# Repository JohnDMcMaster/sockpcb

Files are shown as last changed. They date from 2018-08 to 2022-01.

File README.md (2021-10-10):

# sockext

Chip socket extension cable adapters.
They are primarily intended to be high quality fixtures for invasive chip analysis such as microprobing, laser fault injection, and EM SCA.

Example: BP Microsystems programmers are high quality but physically large.
Unfortunately this large size precludes it from being used to read out a chip on my probe station.
Solution: extend the socket from the programmer via ribbon cable to an adapter board on the probe station (dipext-pin + dipext-sock + cable).

Projects:
  * dipext-sock: converts an IDC connector to a ZIF40 socket. Also adds patch connections
  * dipext-pin: converts DIP40 pins into an IDC connector. Also adds patch connections
  * dipext-pin-r: like above but flips pins for backside analysis
    * WARNING: not updated for new pin order
  * dipspy: patch a chip similar to dipext-sock + dipext-pin w/o cables and such
    * FIXME: needs rev to use SMD to make solder easier

IMPORTANT: pin order was swapped at this rev to match crimp connectors:
  * dipext-sock_r3
  * dipext-pin_r6
  * WARNING: dipext-pin-r_r1 is not compatible / updated yet

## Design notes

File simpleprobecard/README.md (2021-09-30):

# Simple microprobing breakout thing for 0.5mm wide probes
Hole is parametric, can be cut to any size.
Mounting points are on a standard 1" grid.
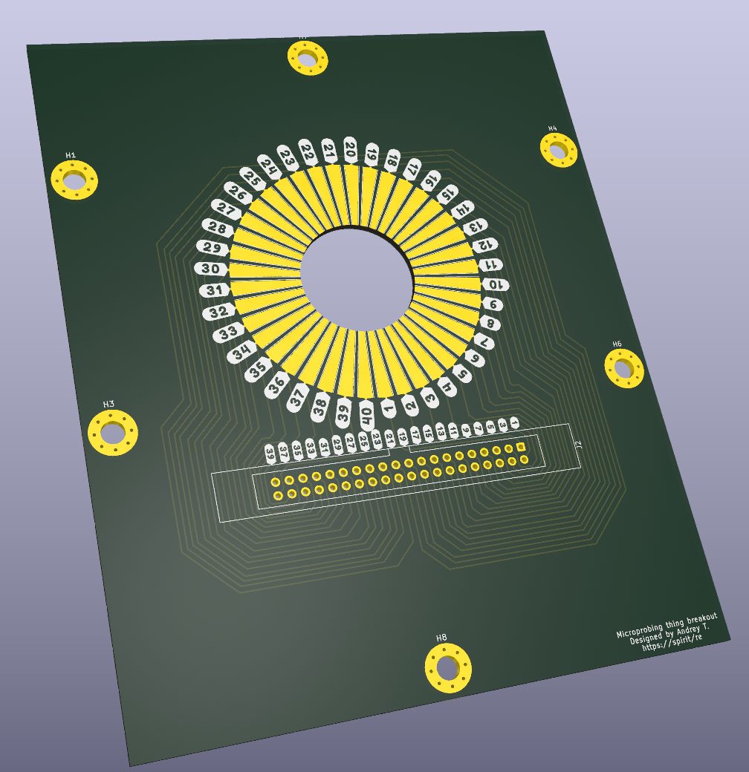
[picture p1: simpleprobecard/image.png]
Render


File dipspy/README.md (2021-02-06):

# dipspy
DIP40 signal parallel and series signal tap.
Usually you'll want jumpers in the center positions to connect the two sockets together.
Alternatively install a current probe, feed in an external signal, etc.
Logic analyzers can be easily attached to the extra pins

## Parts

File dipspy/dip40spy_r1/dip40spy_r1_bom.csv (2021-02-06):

Manufacturer Part Number | Manufacturer | Digi-Key Part Number | Customer Reference | Reference Designator | Packaging | Part Status | Quantity | Unit Price | Extended Price | Quantity Available | Mfg Std Lead Time | Description | RoHS Status | Lead Free Status | REACH Status
CD74HC4050M96 | Texas Instruments | 296-14529-1-ND |  |  | Cut Tape (CT) | Active | 2 | 0.46000 | $0.92 | 22280 | 6 Weeks | IC BUFFER NON-INVERT 6V 16SOIC | RoHS Compliant | Lead free | REACH Unaffected
150060BS75000 | Wurth Electronics Inc. | 732-4966-1-ND |  |  | Cut Tape (CT) | Active | 1 | 0.15000 | $0.15 | 31400 | 10 Weeks | LED BLUE CLEAR 0603 SMD | RoHS Compliant | Lead free | REACH Unaffected
150060VS75000 | Wurth Electronics Inc. | 732-4980-1-ND |  |  | Cut Tape (CT) | Active | 1 | 0.14000 | $0.14 | 53972 | 10 Weeks | LED GREEN CLEAR 0603 SMD | RoHS Compliant | Lead free | REACH Unaffected
SS-60000-008 | Stewart Connector | 380-1095-ND |  |  | Tray | Active | 6 | 3.02000 | $18.12 | 6441 | 16 Weeks | CONN MOD JACK 8P8C VERT SHIELDED | RoHS Compliant | Lead free | REACH Unaffected
TSW-123-07-F-D | Samtec Inc. | SAM12366-ND |  |  | Bulk | Active | 2 | 2.88000 | $5.76 | 264 | 3 Weeks | .025" SQ. TERMINAL STRIPS | RoHS Compliant | Lead free | REACH Unaffected

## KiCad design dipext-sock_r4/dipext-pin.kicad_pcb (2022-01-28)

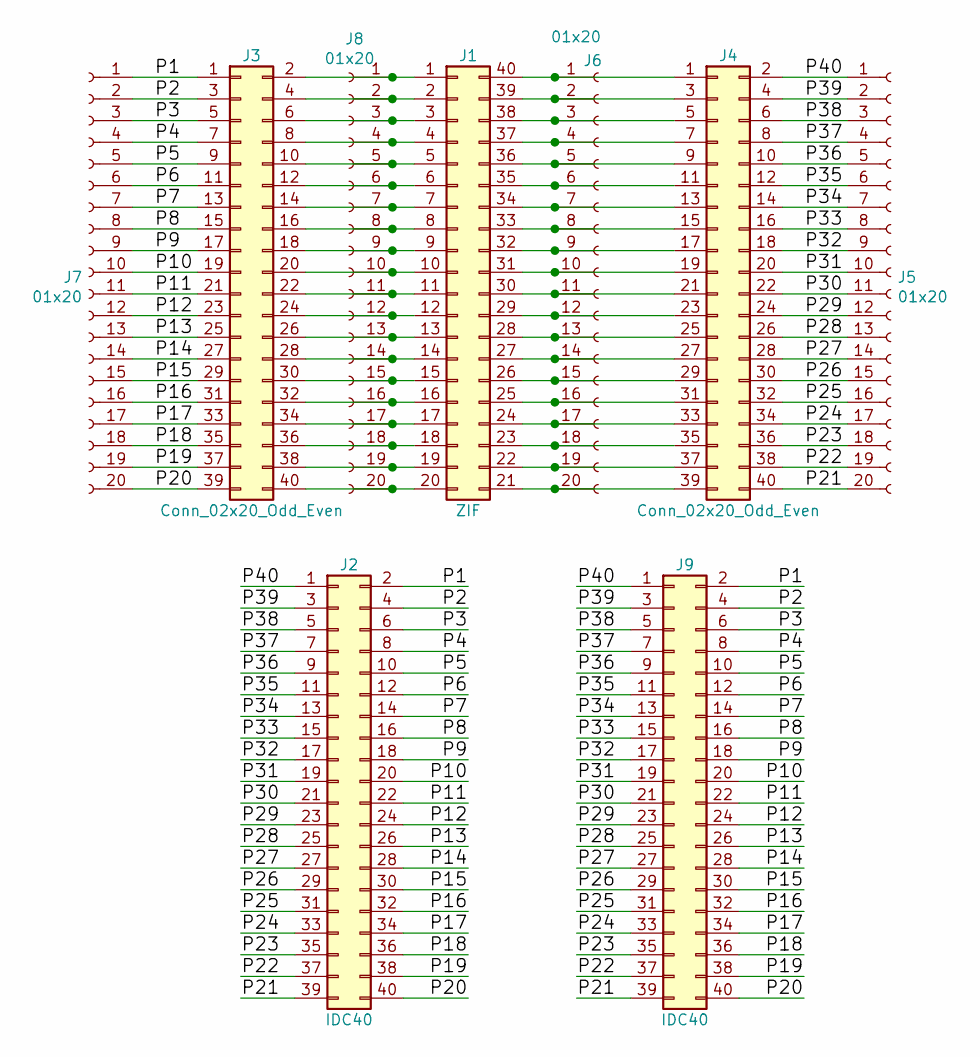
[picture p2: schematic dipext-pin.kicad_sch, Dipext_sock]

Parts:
J1: ZIF; mydip40
J2, J9: IDC40; IDC-Header_2x20_P2.54mm_Latch_Vertical
J3, J4: Conn_02x20_Odd_Even; Pin_Header_Straight_2x20_Pitch2.54mm
J5, J6, J7, J8: 01x20; PinHeader_1x20_P2.54mm_Vertical

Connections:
/P1: J2.2, J3.1, J7.1, J9.2
/P2: J2.4, J3.3, J7.2, J9.4
/P3: J2.6, J3.5, J7.3, J9.6
/P4: J2.8, J3.7, J7.4, J9.8
/P5: J2.10, J3.9, J7.5, J9.10
/P6: J2.12, J3.11, J7.6, J9.12
/P7: J2.14, J3.13, J7.7, J9.14
/P8: J2.16, J3.15, J7.8, J9.16
/P9: J2.18, J3.17, J7.9, J9.18
/P10: J2.20, J3.19, J7.10, J9.20
/P11: J2.22, J3.21, J7.11, J9.22
/P12: J2.24, J3.23, J7.12, J9.24
/P13: J2.26, J3.25, J7.13, J9.26
/P14: J2.28, J3.27, J7.14, J9.28
/P15: J2.30, J3.29, J7.15, J9.30
/P16: J2.32, J3.31, J7.16, J9.32
/P17: J2.34, J3.33, J7.17, J9.34
/P18: J2.36, J3.35, J7.18, J9.36
/P19: J2.38, J3.37, J7.19, J9.38
/P20: J2.40, J3.39, J7.20, J9.40
/P21: J2.39, J4.40, J5.20, J9.39
/P22: J2.37, J4.38, J5.19, J9.37
/P23: J2.35, J4.36, J5.18, J9.35
/P24: J2.33, J4.34, J5.17, J9.33
/P25: J2.31, J4.32, J5.16, J9.31
/P26: J2.29, J4.30, J5.15, J9.29
/P27: J2.27, J4.28, J5.14, J9.27
/P28: J2.25, J4.26, J5.13, J9.25
/P29: J2.23, J4.24, J5.12, J9.23
/P30: J2.21, J4.22, J5.11, J9.21
/P31: J2.19, J4.20, J5.10, J9.19
/P32: J2.17, J4.18, J5.9, J9.17
/P33: J2.15, J4.16, J5.8, J9.15
/P34: J2.13, J4.14, J5.7, J9.13
/P35: J2.11, J4.12, J5.6, J9.11
/P36: J2.9, J4.10, J5.5, J9.9
/P37: J2.7, J4.8, J5.4, J9.7
/P38: J2.5, J4.6, J5.3, J9.5
/P39: J2.3, J4.4, J5.2, J9.3
/P40: J2.1, J4.2, J5.1, J9.1
unnamed: J1.1, J3.2, J8.1
unnamed: J1.2, J3.4, J8.2
unnamed: J1.3, J3.6, J8.3
unnamed: J1.4, J3.8, J8.4
unnamed: J1.5, J3.10, J8.5
unnamed: J1.6, J3.12, J8.6
unnamed: J1.7, J3.14, J8.7
unnamed: J1.8, J3.16, J8.8
unnamed: J1.9, J3.18, J8.9
unnamed: J1.10, J3.20, J8.10
unnamed: J1.11, J3.22, J8.11
unnamed: J1.12, J3.24, J8.12
unnamed: J1.13, J3.26, J8.13
unnamed: J1.14, J3.28, J8.14
unnamed: J1.15, J3.30, J8.15
unnamed: J1.16, J3.32, J8.16
unnamed: J1.17, J3.34, J8.17
unnamed: J1.18, J3.36, J8.18
unnamed: J1.19, J3.38, J8.19
unnamed: J1.20, J3.40, J8.20
unnamed: J1.21, J4.39, J6.20
unnamed: J1.22, J4.37, J6.19
unnamed: J1.23, J4.35, J6.18
unnamed: J1.24, J4.33, J6.17
unnamed: J1.25, J4.31, J6.16
unnamed: J1.26, J4.29, J6.15
unnamed: J1.27, J4.27, J6.14
unnamed: J1.28, J4.25, J6.13
unnamed: J1.29, J4.23, J6.12
unnamed: J1.30, J4.21, J6.11
unnamed: J1.31, J4.19, J6.10
unnamed: J1.32, J4.17, J6.9
unnamed: J1.33, J4.15, J6.8
unnamed: J1.34, J4.13, J6.7
unnamed: J1.35, J4.11, J6.6
unnamed: J1.36, J4.9, J6.5
unnamed: J1.37, J4.7, J6.4
unnamed: J1.38, J4.5, J6.3
unnamed: J1.39, J4.3, J6.2
unnamed: J1.40, J4.1, J6.1

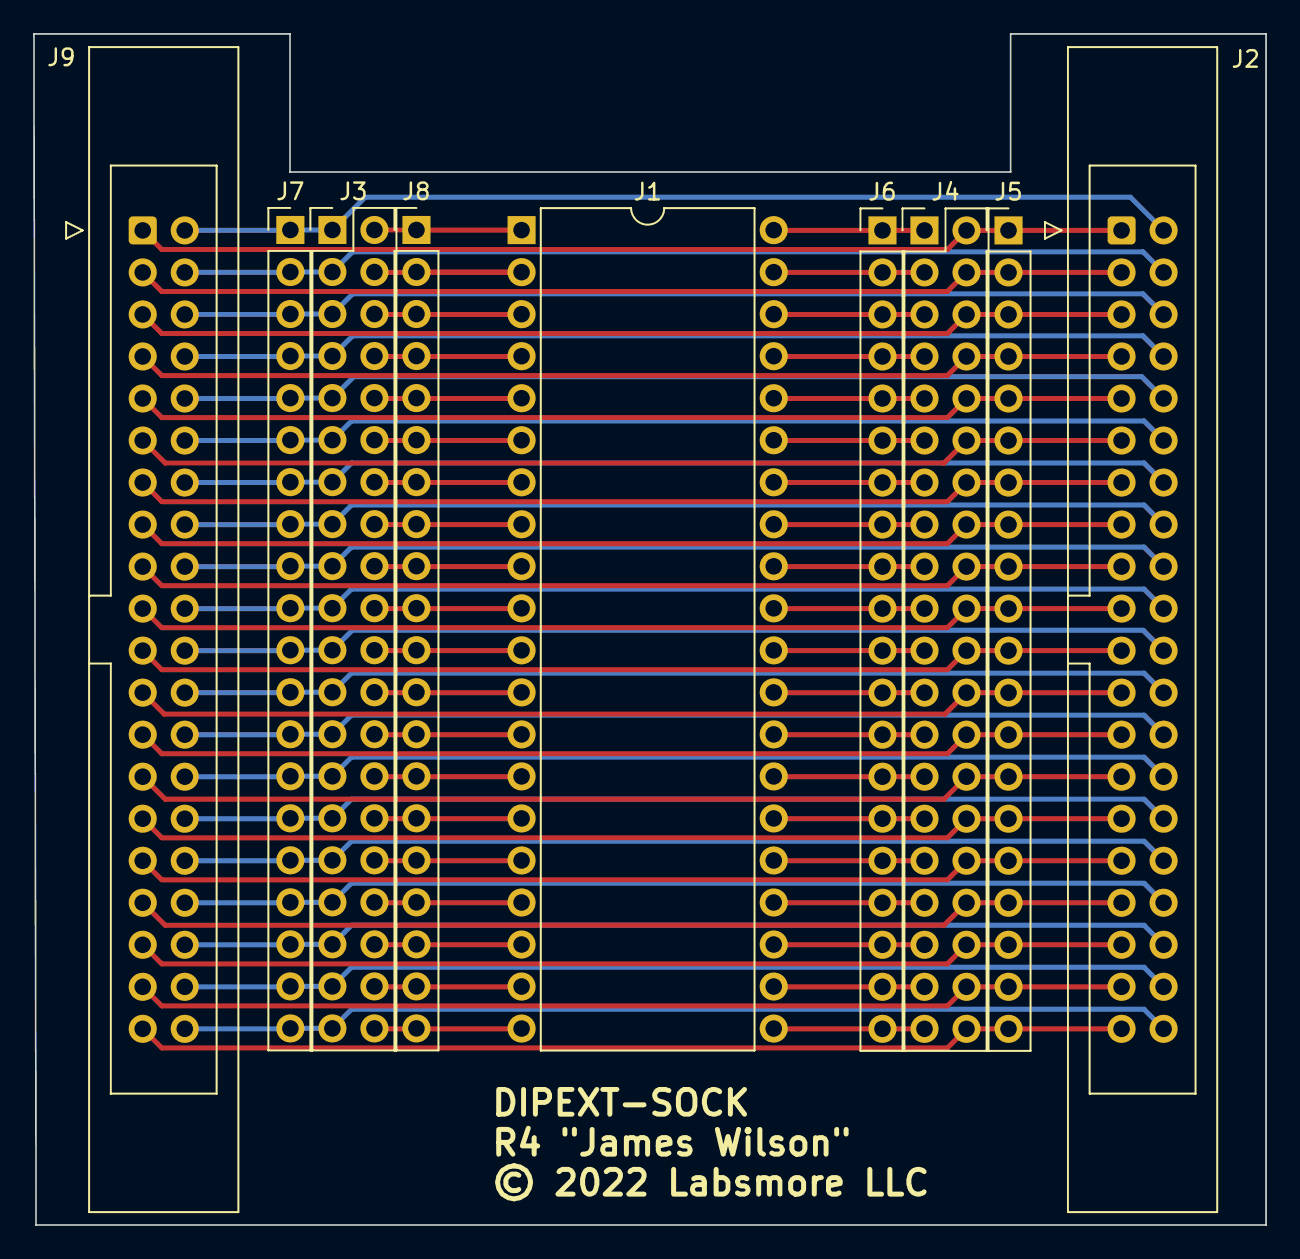
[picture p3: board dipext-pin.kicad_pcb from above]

Board: 2 copper layers, 74.5 x 72.0 mm, 9 parts (0 on the bottom side), 80 nets.

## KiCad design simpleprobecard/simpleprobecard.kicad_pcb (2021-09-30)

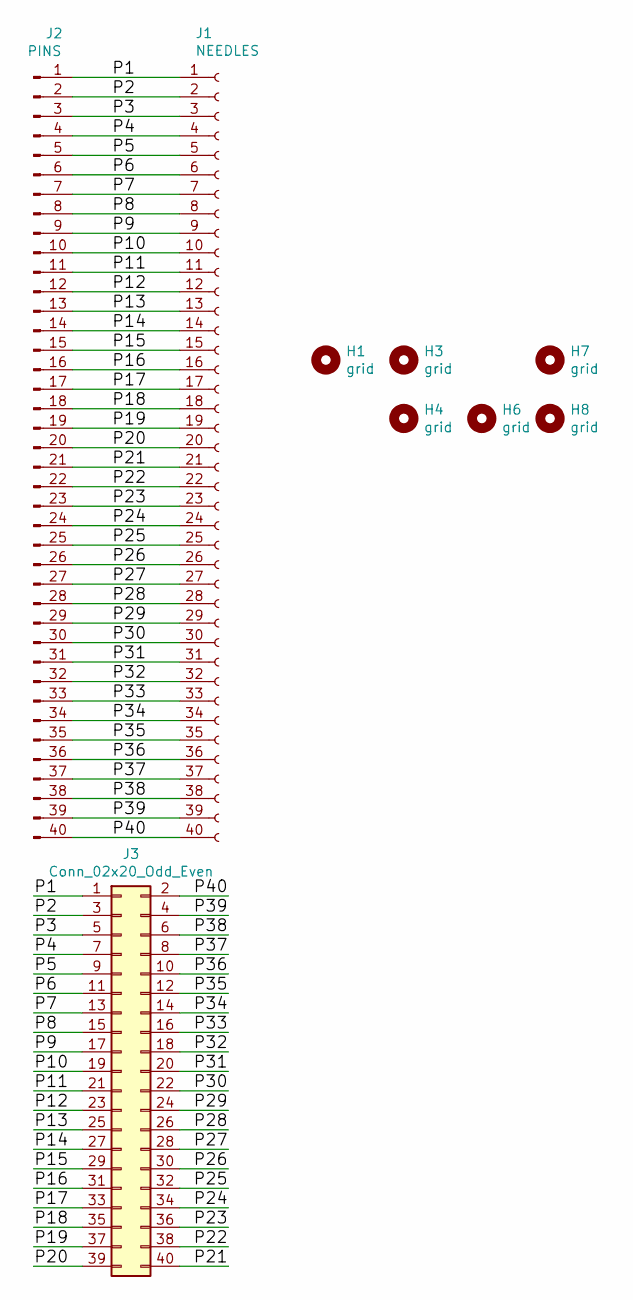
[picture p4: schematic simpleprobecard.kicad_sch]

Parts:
H1, H3, H4, H6, H7, H8: grid; MountingHole_4.3mm_M4_Pad_Via
J1: NEEDLES; Pin
J2: PINS; IDC-Header_2x20_P2.54mm_Latch_Vertical
J3: Conn_02x20_Odd_Even; IDC-Header_2x20_P2.54mm_Latch_Vertical

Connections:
/P1: J1.1, J2.1, J3.1
/P2: J1.2, J2.2, J3.3
/P3: J1.3, J2.3, J3.5
/P4: J1.4, J2.4, J3.7
/P5: J1.5, J2.5, J3.9
/P6: J1.6, J2.6, J3.11
/P7: J1.7, J2.7, J3.13
/P8: J1.8, J2.8, J3.15
/P9: J1.9, J2.9, J3.17
/P10: J1.10, J2.10, J3.19
/P11: J1.11, J2.11, J3.21
/P12: J1.12, J2.12, J3.23
/P13: J1.13, J2.13, J3.25
/P14: J1.14, J2.14, J3.27
/P15: J1.15, J2.15, J3.29
/P16: J1.16, J2.16, J3.31
/P17: J1.17, J2.17, J3.33
/P18: J1.18, J2.18, J3.35
/P19: J1.19, J2.19, J3.37
/P20: J1.20, J2.20, J3.39
/P21: J1.21, J2.21, J3.40
/P22: J1.22, J2.22, J3.38
/P23: J1.23, J2.23, J3.36
/P24: J1.24, J2.24, J3.34
/P25: J1.25, J2.25, J3.32
/P26: J1.26, J2.26, J3.30
/P27: J1.27, J2.27, J3.28
/P28: J1.28, J2.28, J3.26
/P29: J1.29, J2.29, J3.24
/P30: J1.30, J2.30, J3.22
/P31: J1.31, J2.31, J3.20
/P32: J1.32, J2.32, J3.18
/P33: J1.33, J2.33, J3.16
/P34: J1.34, J2.34, J3.14
/P35: J1.35, J2.35, J3.12
/P36: J1.36, J2.36, J3.10
/P37: J1.37, J2.37, J3.8
/P38: J1.38, J2.38, J3.6
/P39: J1.39, J2.39, J3.4
/P40: J1.40, J2.40, J3.2

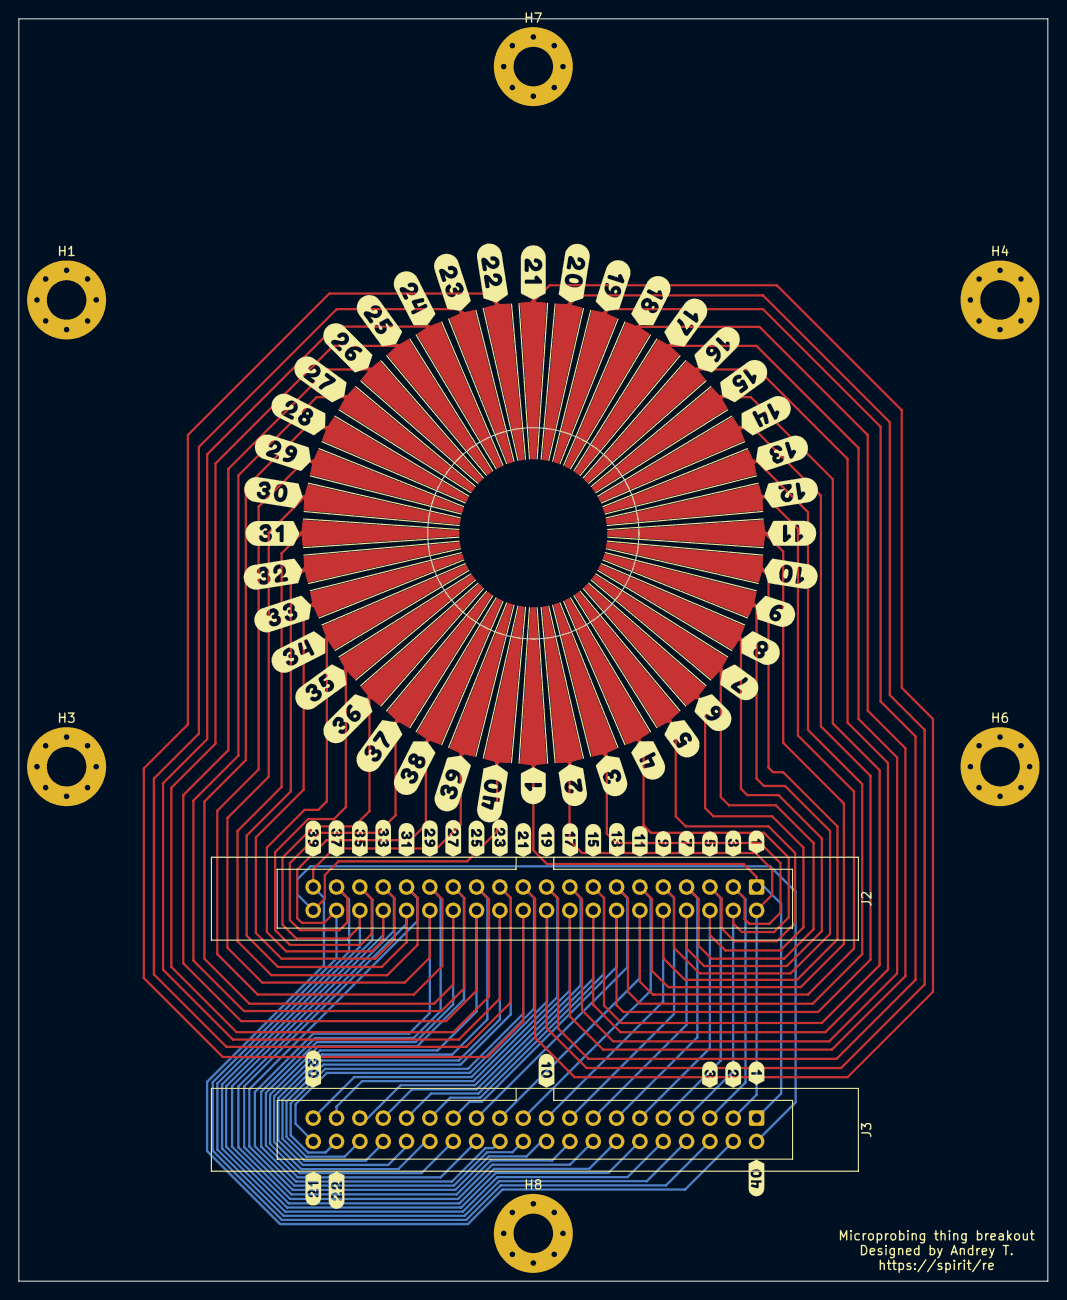
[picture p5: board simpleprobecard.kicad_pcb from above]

Board: 2 copper layers, 112.0 x 137.4 mm, 9 parts (0 on the bottom side), 40 nets.

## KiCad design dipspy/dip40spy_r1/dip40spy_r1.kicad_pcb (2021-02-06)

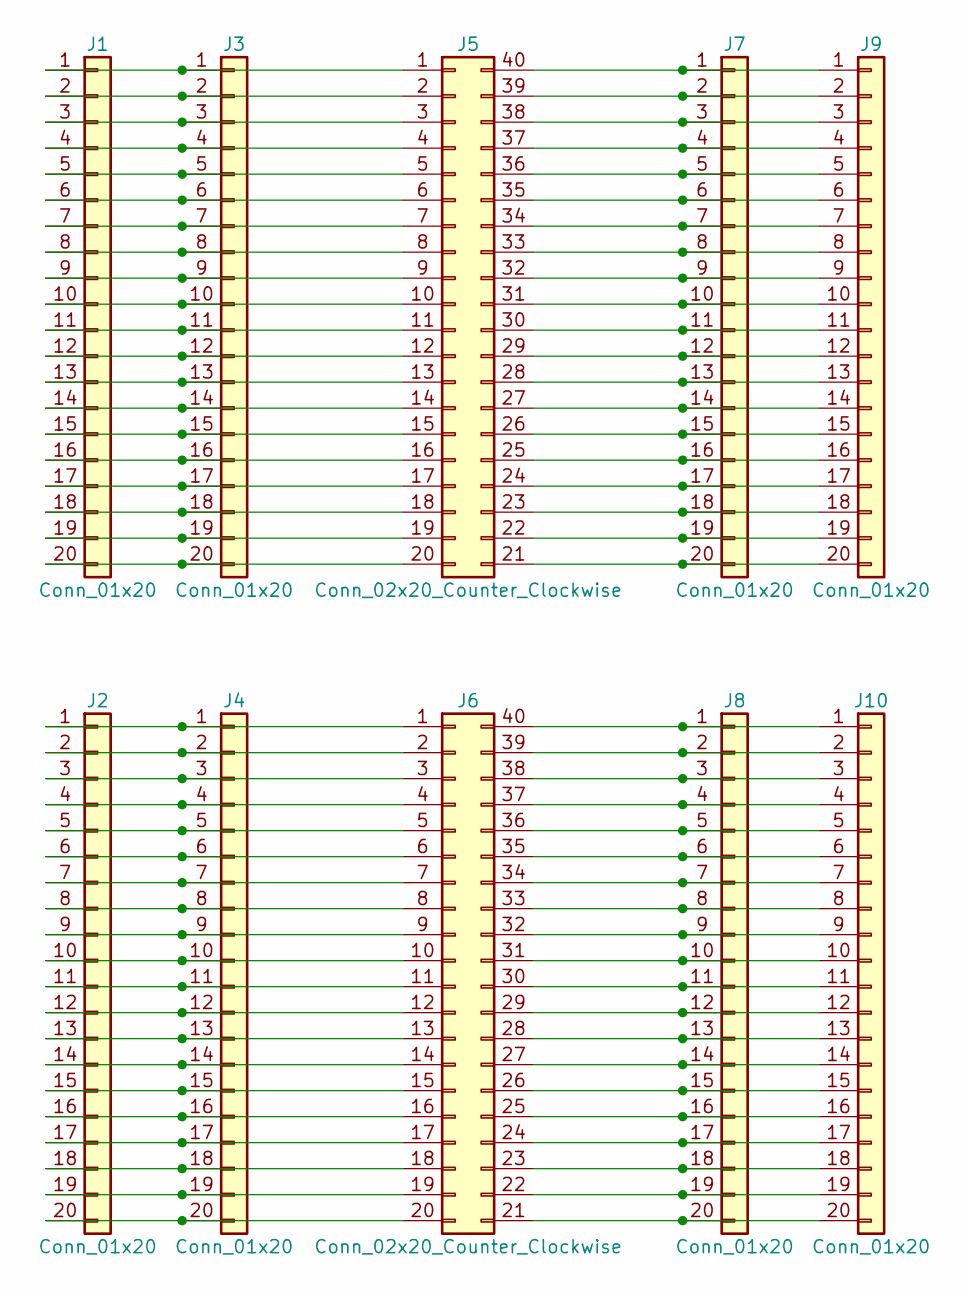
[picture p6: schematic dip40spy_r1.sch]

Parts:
J1, J2, J3, J4, J7, J8, J9, J10: Conn_01x20; Pin_Header_Straight_1x20_Pitch2.54mm
J5: Conn_02x20_Counter_Clockwise; aries_40-6554-10_DIP-40_W15.24mm_ZIF
J6: Conn_02x20_Counter_Clockwise; dip40-0.3

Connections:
unnamed: J1.1, J3.1, J5.1
unnamed: J1.2, J3.2, J5.2
unnamed: J1.3, J3.3, J5.3
unnamed: J1.4, J3.4, J5.4
unnamed: J1.5, J3.5, J5.5
unnamed: J1.6, J3.6, J5.6
unnamed: J1.7, J3.7, J5.7
unnamed: J1.8, J3.8, J5.8
unnamed: J1.9, J3.9, J5.9
unnamed: J1.10, J3.10, J5.10
unnamed: J1.11, J3.11, J5.11
unnamed: J1.12, J3.12, J5.12
unnamed: J1.13, J3.13, J5.13
unnamed: J1.14, J3.14, J5.14
unnamed: J1.15, J3.15, J5.15
unnamed: J1.16, J3.16, J5.16
unnamed: J1.17, J3.17, J5.17
unnamed: J1.18, J3.18, J5.18
unnamed: J1.19, J3.19, J5.19
unnamed: J1.20, J3.20, J5.20
unnamed: J2.1, J4.1, J6.1
unnamed: J2.2, J4.2, J6.2
unnamed: J2.3, J4.3, J6.3
unnamed: J2.4, J4.4, J6.4
unnamed: J2.5, J4.5, J6.5
unnamed: J2.6, J4.6, J6.6
unnamed: J2.7, J4.7, J6.7
unnamed: J2.8, J4.8, J6.8
unnamed: J2.9, J4.9, J6.9
unnamed: J2.10, J4.10, J6.10
unnamed: J2.11, J4.11, J6.11
unnamed: J2.12, J4.12, J6.12
unnamed: J2.13, J4.13, J6.13
unnamed: J2.14, J4.14, J6.14
unnamed: J2.15, J4.15, J6.15
unnamed: J2.16, J4.16, J6.16
unnamed: J2.17, J4.17, J6.17
unnamed: J2.18, J4.18, J6.18
unnamed: J2.19, J4.19, J6.19
unnamed: J2.20, J4.20, J6.20
unnamed: J5.21, J7.20, J9.20
unnamed: J5.22, J7.19, J9.19
unnamed: J5.23, J7.18, J9.18
unnamed: J5.24, J7.17, J9.17
unnamed: J5.25, J7.16, J9.16
unnamed: J5.26, J7.15, J9.15
unnamed: J5.27, J7.14, J9.14
unnamed: J5.28, J7.13, J9.13
unnamed: J5.29, J7.12, J9.12
unnamed: J5.30, J7.11, J9.11
unnamed: J5.31, J7.10, J9.10
unnamed: J5.32, J7.9, J9.9
unnamed: J5.33, J7.8, J9.8
unnamed: J5.34, J7.7, J9.7
unnamed: J5.35, J7.6, J9.6
unnamed: J5.36, J7.5, J9.5
unnamed: J5.37, J7.4, J9.4
unnamed: J5.38, J7.3, J9.3
unnamed: J5.39, J7.2, J9.2
unnamed: J5.40, J7.1, J9.1
unnamed: J6.40, J8.1, J10.1
unnamed: J6.39, J8.2, J10.2
unnamed: J6.38, J8.3, J10.3
unnamed: J6.37, J8.4, J10.4
unnamed: J6.36, J8.5, J10.5
unnamed: J6.35, J8.6, J10.6
unnamed: J6.34, J8.7, J10.7
unnamed: J6.33, J8.8, J10.8
unnamed: J6.32, J8.9, J10.9
unnamed: J6.31, J8.10, J10.10
unnamed: J6.30, J8.11, J10.11
unnamed: J6.29, J8.12, J10.12
unnamed: J6.28, J8.13, J10.13
unnamed: J6.27, J8.14, J10.14
unnamed: J6.26, J8.15, J10.15
unnamed: J6.25, J8.16, J10.16
unnamed: J6.24, J8.17, J10.17
unnamed: J6.23, J8.18, J10.18
unnamed: J6.22, J8.19, J10.19
unnamed: J6.21, J8.20, J10.20

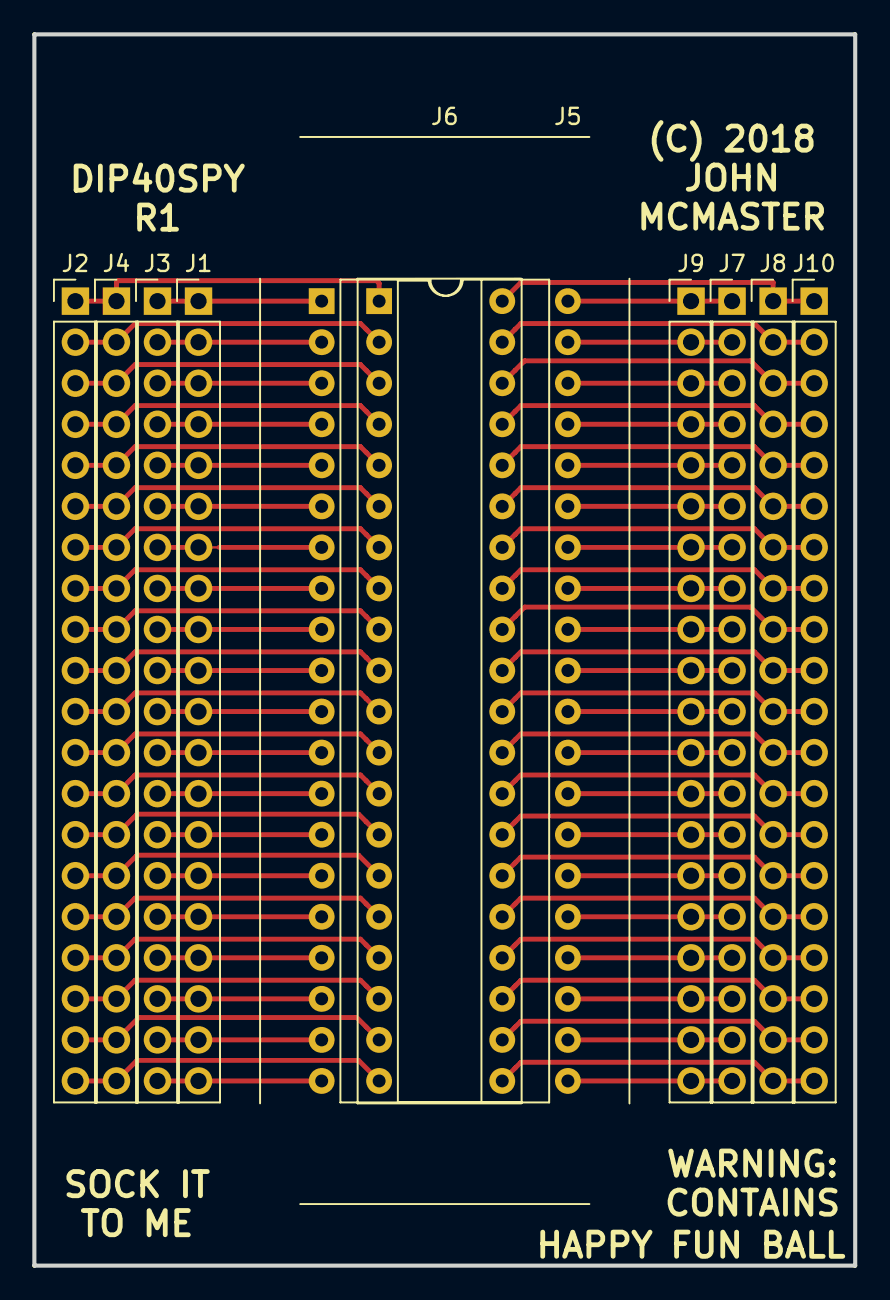
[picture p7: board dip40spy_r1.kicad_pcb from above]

Board: 2 copper layers, 50.8 x 76.2 mm, 10 parts (0 on the bottom side), 80 nets.

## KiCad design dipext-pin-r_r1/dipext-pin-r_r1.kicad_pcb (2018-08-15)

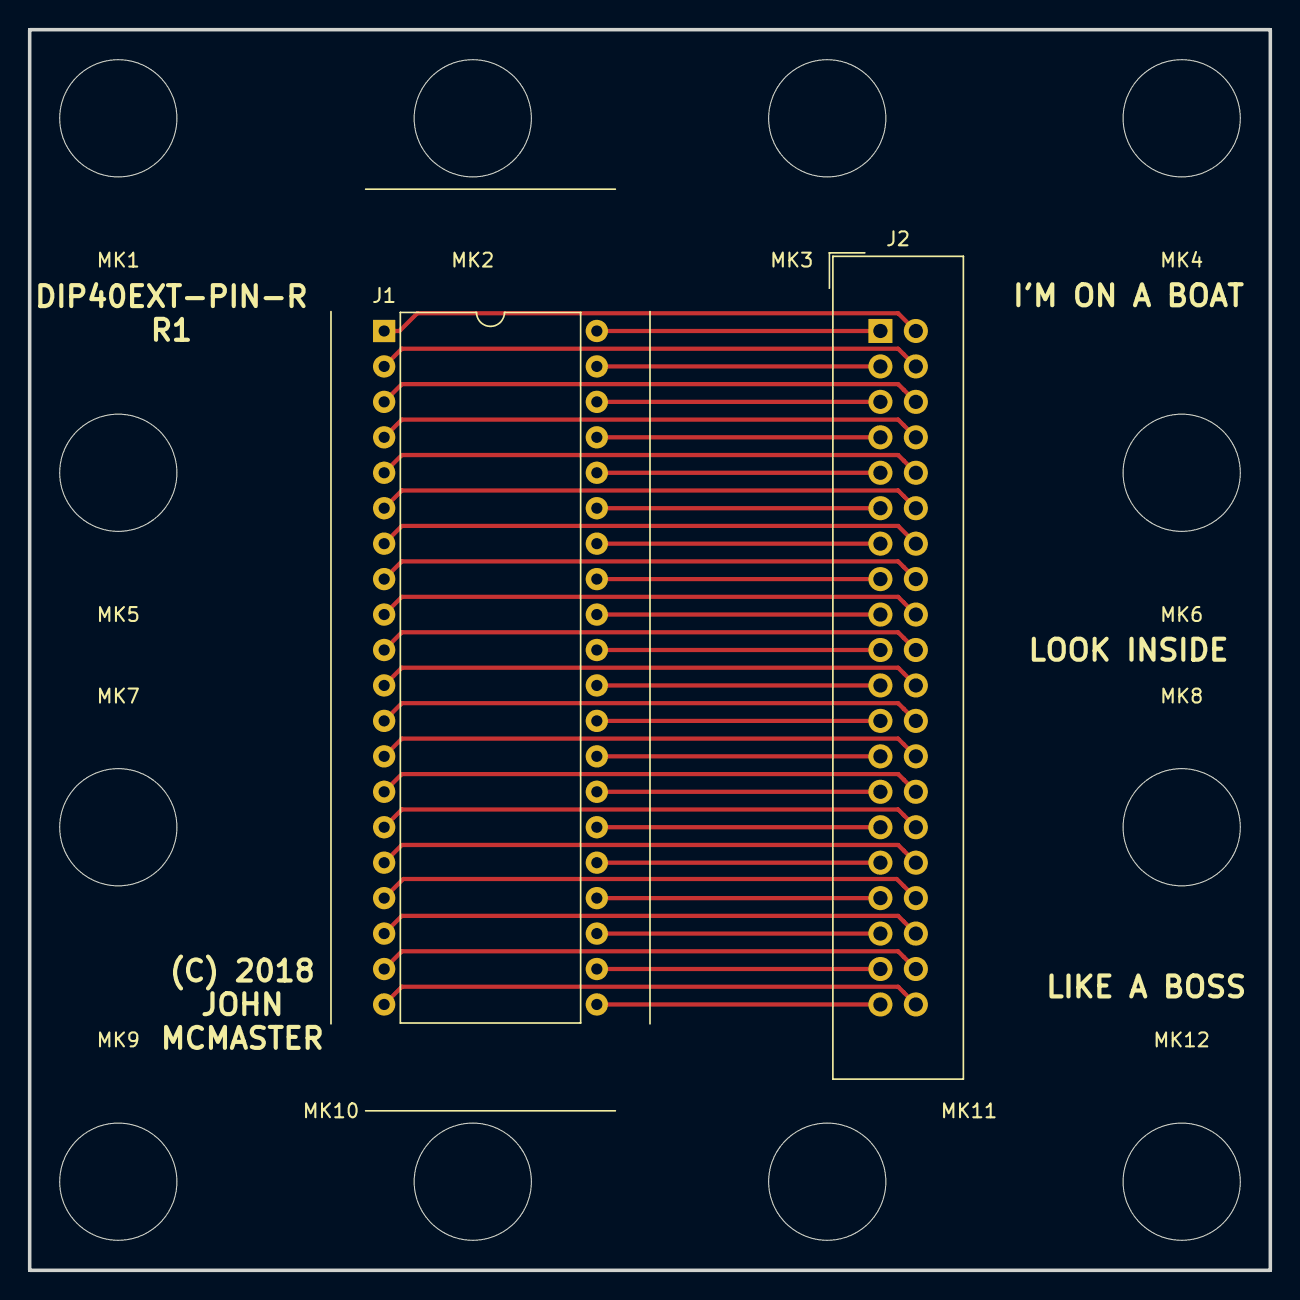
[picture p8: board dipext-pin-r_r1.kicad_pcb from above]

Board: 2 copper layers, 88.9 x 88.9 mm, 14 parts (0 on the bottom side), 40 nets.

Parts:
J1: ZIF; aries_40-6554-10_DIP-40_W15.24mm_ZIF
J2: IDC40; IDC-Header_2x20_Pitch2.54mm_Straight
MK1, MK2, MK3, MK4, MK5, MK6, MK7, MK8, MK9, MK10, MK11, MK12: Mounting_Hole; MountingHole_8.4mm_M8

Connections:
/P1: J1.1, J2.2
/P2: J1.2, J2.4
/P3: J1.3, J2.6
/P4: J1.4, J2.8
/P5: J1.5, J2.10
/P6: J1.6, J2.12
/P7: J1.7, J2.14
/P8: J1.8, J2.16
/P9: J1.9, J2.18
/P10: J1.10, J2.20
/P11: J1.11, J2.22
/P12: J1.12, J2.24
/P13: J1.13, J2.26
/P14: J1.14, J2.28
/P15: J1.15, J2.30
/P16: J1.16, J2.32
/P17: J1.17, J2.34
/P18: J1.18, J2.36
/P19: J1.19, J2.38
/P20: J1.20, J2.40
/P21: J1.21, J2.39
/P22: J1.22, J2.37
/P23: J1.23, J2.35
/P24: J1.24, J2.33
/P25: J1.25, J2.31
/P26: J1.26, J2.29
/P27: J1.27, J2.27
/P28: J1.28, J2.25
/P29: J1.29, J2.23
/P30: J1.30, J2.21
/P31: J1.31, J2.19
/P32: J1.32, J2.17
/P33: J1.33, J2.15
/P34: J1.34, J2.13
/P35: J1.35, J2.11
/P36: J1.36, J2.9
/P37: J1.37, J2.7
/P38: J1.38, J2.5
/P39: J1.39, J2.3
/P40: J1.40, J2.1

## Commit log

2021-02-06 import dipspy
    [dip40spy_r1-B.Cu.gbr, dip40spy_r1-B.Mask.gbr, dip40spy_r1-B.SilkS.gbr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]
2021-02-06 Revert "Yes."
    This reverts commit 611ce2b3961d5ca419525b40e4a89030cbd90d7e.
    deleted: dipext-pin_r4/Gerbers.zip
    deleted: dipext-pin_r4/Gerbers/dipext-pin_r4-B_Cu.gbr
    deleted: dipext-pin_r4/Gerbers/dipext-pin_r4-B_Mask.gbr
    deleted: dipext-pin_r4/Gerbers/dipext-pin_r4-B_Silkscreen.gbr
    deleted: dipext-pin_r4/Gerbers/dipext-pin_r4-Edge_Cuts.gbr
    deleted: dipext-pin_r4/Gerbers/dipext-pin_r4-F_Cu.gbr
    deleted: dipext-pin_r4/Gerbers/dipext-pin_r4-F_Mask.gbr
    deleted: dipext-pin_r4/Gerbers/dipext-pin_r4-F_Silkscreen.gbr
    deleted: dipext-pin_r4/Gerbers/dipext-pin_r4-NPTH-drl_map.ps
    deleted: dipext-pin_r4/Gerbers/dipext-pin_r4-NPTH.drl
    deleted: dipext-pin_r4/Ger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
    [dipext-pin_r4-2021-02-06-23-54-14.sch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]
2021-02-06 Yes 2, but now R5.
    [dipext-pin_r4-2021-02-06-23-54-14.sch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]
2021-02-06 2.54 pitch spacing
    [dipext-pin_r4-B_Cu.gbr, dipext-pin_r4-B_Mask.gbr, dipext-pin_r4-B_Silkscreen.gbr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]
2021-02-07 First version of the simple microprobing board
    deleted: dipext-pin_r5/dipext-pin_r4-backups/dipext-pin_r4-2021-02-07_002243.zip
    deleted: dipext-pin_r5/dipext-pin_r4-backups/dipext-pin_r4-2021-02-07_010020.zip
    deleted: dipext-pin_r5/rescue-backup/dipext-pin_r4-2021-02-06-23-54-14.kicad_pro
    deleted: dipext-pin_r5/rescue-backup/dipext-pin_r4-2021-02-06-23-54-14.sch
    deleted: dipext-pin_r5/rescue-backup/dipext-pin_r4-cache-2021-02-06-23-54-14.lib
    new file: simpleprobecard/Gerbers.zip
    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
    [dipext-pin_r4-2021-02-06-23-54-14.sch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]
2021-02-07 modified: dipext-pin_r4/dipext-pin_r4.kicad_pcb modified: dipext-pin_r4/dipext-pin_r4.kicad_prl modified: dipext-pin_r4/dipext-pin_r4.kicad_pro modified: dipext-pin_r5/dipext-pin_r4.kicad_prl modifie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
    [dipext-pin_r4.kicad_pcb, dipext-pin_r4.kicad_sch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]
2021-08-29 Adding R6. Has swapped pins so that Pin1(ribbon)->Pin40(IDC). Some minor cleanup and fixes.
    [dipext-pin_r4.kicad_pcb, dipext-pin_r4.kicad_sch, dipext-pin_r4.sch]
2021-09-30 dipext-pin_r6: simplify mounting holes
    [dipext-pin_r4.kicad_pcb, dipext-pin_r4.kicad_sch]
2021-09-30 renamve r4 suffix
    [dipext-pin.kicad_pcb, dipext-pin.kicad_sch, dipext-pin.sch]
2021-10-01 Adding dipext-sock_r3.
    Converted the r2 altium pcb files to kicad. Rewired the traces to match the flipping of the connections similar to the corresponding changes in dipext-pin R6. Note: had to suspend the DRC checks, since the schematic did not import and so had to route againt the netlist thats in the pcb file. Note2: the "import non-kicad" option to import altium files only shows up in pcbnew if you start pcbnew directly, and not through the project explorer of kicad."
    [dipext-sock.kicad_pcb, dipext-sock.kicad_sch]
2021-10-07 Recreating dipext-sock R3 from: dipext-pin R6, with new cut lines and mounting holes removed.
    [dipext-pin.kicad_pcb, dipext-pin.kicad_sch, dipext-pin.sch]
2021-10-07 Removing old files.
    [dipext-sock.kicad_pcb, dipext-sock.kicad_sch]
2021-10-07 Fixing schematic info block.
    [dipext-pin.kicad_sch]
2021-10-10 Fixes to cut lines.
    [dipext-pin.kicad_pcb]
2022-01-28 Adding R4. Added additional header, changed board outline
    [dipext-pin.kicad_pcb, dipext-pin.kicad_sch]

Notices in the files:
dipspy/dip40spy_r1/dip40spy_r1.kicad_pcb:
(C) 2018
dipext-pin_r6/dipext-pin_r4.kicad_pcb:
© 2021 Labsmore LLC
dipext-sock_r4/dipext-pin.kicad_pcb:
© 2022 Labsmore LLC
